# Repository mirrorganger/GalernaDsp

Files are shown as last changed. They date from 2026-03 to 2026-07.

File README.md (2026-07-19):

# Galerna DSP



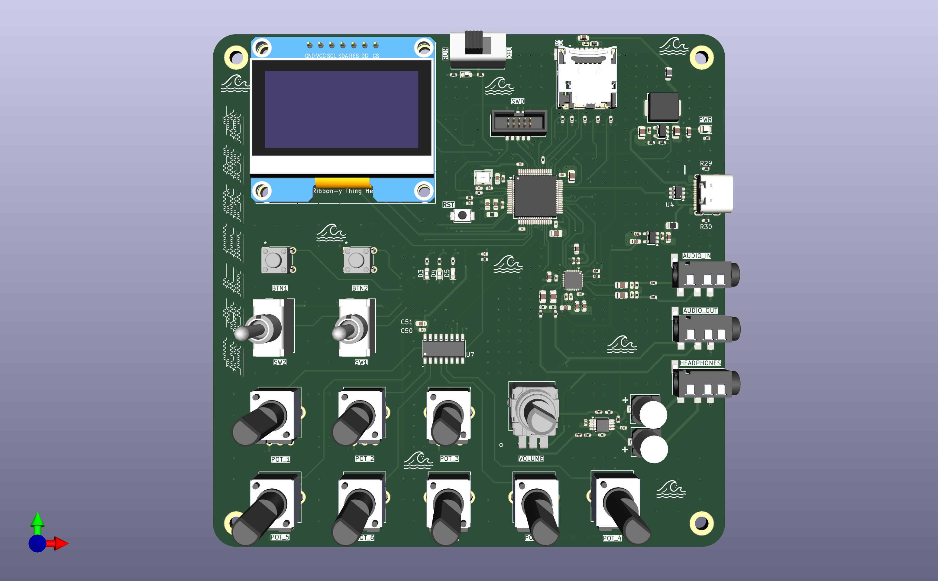
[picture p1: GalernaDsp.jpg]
Galerna DSP board render


Galerna DSP is a KiCad hardware project for an STM32-based audio effects board: two
audio channels in/out, 8 potentiometers, footswitches/buttons, an OLED display, and a
microSD slot, all built around an STM32F405.

Full design write-up — requirements, as-built BOM, power budget, codec/amp circuit
notes — lives in **[docs/Design.md](docs/Design.md)**.

## Repository layout

| Path | Contents |
|---|---|
| `GalernaDsp.kicad_pro` / `.kicad_pcb` / `.kicad_sch` | Top-level KiCad project and root schematic sheet |
| `power.kicad_sch`, `mcu.kicad_sch`, `audio_codec.kicad_sch`, `input_control.kicad_sch` | The four schematic sub-sheets |
| `libraries/Galerna/` | Project-specific KiCad symbol/footprint/3D-model library |
| `cubeMx/` | STM32CubeMX-generated firmware project for the STM32F405RGT6 (peripheral init only, no application code yet) |
| `jlcpcb/` | Manufacturing outputs for JLCPCB: gerbers, drill files, BOM/CPL for assembly |
| `docs/` | Design documentation |
| `GalernaDsp.xlsx` / `.csv` | Bill of materials |

## Opening the project

Open `GalernaDsp.kicad_pro` in KiCad (7.x). The root schematic pulls in the four
sub-sheets listed above; the PCB is a single `GalernaDsp.kicad_pcb`.

## Firmware

`cubeMx/` is a standard STM32CubeMX + CMake project. Regenerate from `cubeMx/Galerna.ioc`
in STM32CubeMX if peripheral config changes; build with CMake/CMakePresets as usual for
an STM32F4 target.

## Manufacturing

Gerbers, drill files, and JLCPCB assembly data (BOM/CPL) are pre-generated under
`jlcpcb/production_files/`.

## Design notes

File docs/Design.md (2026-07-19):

# Galerna DSP — Design

Galerna DSP is a DSP effects board based on the STM32F405, intended to process two
audio channels in real time (guitar/line-level effects unit style: pots + footswitches +
OLED status display).

This document describes the board as actually implemented in the KiCad project. Where the
build diverged from the original requirements, that's called out explicitly.

## Requirements (original intent)

- Two audio channels input/output.
- 48 kHz / up to 24-bit sample width.
- 8 potentiometers, read through a multiplexer.
- 2 mechanical switches.
- 2 buttons.
- USB-C powered.
- SWD debug.
- OLED screen.
- IO extension header.

## As-built summary

- Two audio channels in/out over I2S, plus a dedicated headphone output — a headphone
  amplifier was added, which was not in the original "no audio amplification" requirement.
- 8 potentiometers wired through a CD4051 analog mux to a single ADC input.
- 2 mechanical switches + 2 buttons for footswitch-style control.
- USB-C powered, split into a digital 3.3 V buck rail and a clean analog 3.3 V LDO rail.
- SPI OLED status display.
- microSD card slot (SDIO) for storage — not in the original requirements list.
- SWD debug and IO expansion share a single 2×5, 1.27 mm JST-GH header (CN1).
- 4-layer PCB, no analog/digital ground split, no controlled impedance (USB FS is the
  only differential pair, and it isn't critical).

## Schematic sheets

The KiCad project (`GalernaDsp.kicad_sch`) is split into four sub-sheets:

| Sheet | File | Contents |
|---|---|---|
| Power | `power.kicad_sch` | USB-C input, ESD protection, buck + LDO regulators |
| MCU | `mcu.kicad_sch` | STM32F405RGT6, crystal, OLED, microSD, IO/SWD header, reset/power switches |
| Audio | `audio_codec.kicad_sch` | Audio codec, headphone amplifier, audio jacks |
| Input Control | `input_control.kicad_sch` | 8 potentiometers, mux, footswitches, buttons |

## Bill of materials (as built)

| Function | Part | Reference(s) | Notes |
|---|---|---|---|
| Microcontroller | STM32F405RGT6 (LQFP-64) | U (mcu) | Matches original plan |
| Audio codec | **ES8388** | U (audio) | **Changed from the originally planned WM8731SEDS** during layout (see commit "Codec updated to ES8388") |
| Headphone amplifier | TPA6110A2DGN | U (audio) | Added — original requirements said "no audio amplification" |
| Headphone volume pot | RK09L12D0A1W | R16 | Local pot for headphone amp gain |
| OLED display | ER-OLEDM015-SPI | — | SPI display module; **changed from the originally planned SSD1306 part** (verify controller compatibility before reusing old pin-mapping notes) |
| Effect potentiometers ×8 | PTV09A-4225F-B104 | POT_1…POT_8 | Read through the mux below |
| Analog mux | CD4051BM | — | Routes the 8 pots to a single ADC channel |
| Mechanical switches ×2 | 100SP1T1B4M2QE | SW1, SW2 | |
| Buttons ×2 | 1825910-6 | BTN1, BTN2 | |
| Boot mode switch (RUN/DFU) | SS12D10G5 | SW_1 | Selects BOOT0 state |
| Reset button | TS-1088-AR02016 | SW_2 | |
| Audio jacks ×3 | AudioJack4 (3.5 mm) | J2, J3, J4 | Line in, line out, headphone out |
| microSD slot | HRS DM3CS-SF | J1 | Right-angle SMT microSD holder, on SDIO |
| SWD / IO expansion header | JST-GH 2×5, 1.27 mm | CN1 | Shared header for debug + expansion |
| Crystal | X1E000210127000G | X1 | MCU clock |
| USB-C receptacle | USB4105-GF-A (generic KiCad symbol) | — | |
| ESD protection (USB) | USBLC6-2SC6 | — | |
| ESD protection array (MCU IO) | RCLAMP0521P-N | — | |
| Buck regulator (digital 3V3) | TLV62569DBV | — | |
| LDO regulator (analog 3V3) | SPX3819M5-L-3-3 | — | |

Full BOM with LCSC part numbers lives in `GalernaDsp.csv` at the project root, and
JLCPCB assembly data lives in `jlcpcb/production_files/`.

## Power section

Power comes in over USB-C and is split into two 3.3 V rails:

- **3V3_D** (digital) — switching buck regulator, TLV62569DBV.
- **3V3_A** (analog) — LDO, SPX3819M5-L-3-3, feeding the codec's analog domain for lower
  noise than the buck rail could provide.

### Current budget (3.3 V rails)

| Rail | Load | Estimate |
|---|---|---|
| 3V3_D | STM32F405 | 90–130 mA |
| 3V3_D | OLED | 5–25 mA |
| 3V3_D | Mux + pullups, misc | 5–15 mA |
| 3V3_D | **Budget** | **~200 mA** |
| 3V3_A | Audio codec | ~20 mA typical |
| 3V3_A | **Budget** | **~25–50 mA** |

Total ≈ 250 mA at 3.3 V (≈ 0.83 W). At 85–92% buck efficiency that's roughly 180–200 mA
drawn from 5 V USB — comfortably inside USB power limits.

### Analog rail filtering

After the LDO, a ferrite bead plus local decoupling filters the MCU's `VDDA` pin (ferrite
beads add impedance at high frequency, keeping switching noise off the analog supply):

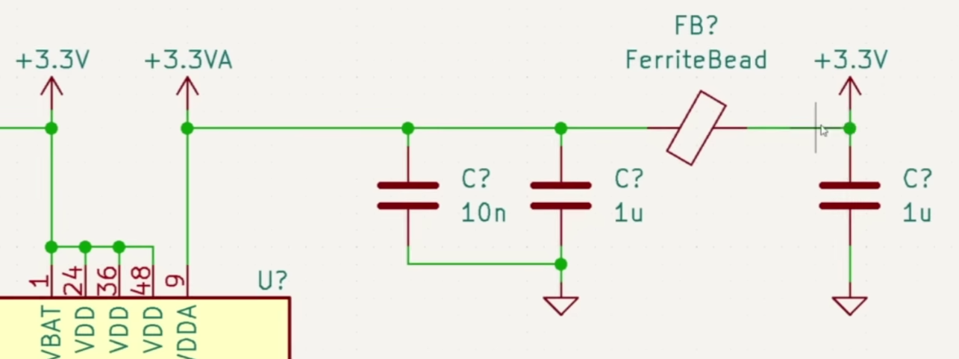
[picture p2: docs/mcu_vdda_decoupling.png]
MCU VDDA decoupling


### Buck converter inductor selection

$$
L = \frac{V_{out} \cdot (V_{in} - V_{out})}{V_{in} \cdot f_{sw} \cdot \Delta I_L}
$$

Where $\Delta I_L$ (inductor ripple current) is targeted at 20–30% of max output current.

- $V_{out} = 3.3\text{V}$, $V_{in} = 4.5$–$5\text{V}$, $f_{sw} = 1.5\text{MHz}$, $I_{max} = 250\text{mA}$
- $\Delta I_L = 0.200\text{A} \times 0.25 = 0.0625\text{A}$
- Calculated $L \approx 12\mu H$ → used a 10 µH inductor.

### Fuse options considered

- Littelfuse 0603L050YR — 500 mA hold, 0603, easiest SMT routing.
- 1206 SMD 500 mA PPTC — larger pads, easier hand/JLC assembly.
- 1210 0.5 A resettable fuse — most robust, needs more board space.

## Audio codec (ES8388)

Use LINE IN, not MIC IN.

### Decoupling

Per supply pin: 1× 100 nF MLCC at the pin (shortest loop to GND). Per rail (shared): 1×
bulk cap (4.7–10 µF) near the codec.

- Digital: 10 µF bulk + 100 nF on DVDD + 100 nF on DBVDD.
- Analog: 10 µF bulk + 100 nF on AVDD + 100 nF on HPVDD (HPVDD unused on this board).

### Input path

```
AUDIO_IN → 1k → ● → 2.2µF → CODEC_IN
                 │
                 ├─ 200k → GND
                 └─ 220p → GND
```

- **2.2 µF AC coupling**: blocks DC, lets the codec bias the input to VMID. Forms a
  high-pass with the codec's ~20–30 kΩ input impedance: $f_c \approx 3.6\text{Hz}$, well
  below the audio band.
- **200 kΩ to GND**: discharge path for the coupling cap; sets input impedance with
  nothing plugged in.
- **220 pF / 1 kΩ RF filter**: rolls off RF picked up by the cable ($f_c \approx 723\text{kHz}$);
  the resistor also limits current during ESD events.

### Output path

Concerns between the codec and the 3.5 mm jacks: DC compatibility (codec biased to
VMID ≈ 1.65 V, jack is 0 V), RF/EMI filtering, output impedance/stability, and
protection against ESD/hot-plugging.

- **AC coupling (~1 µF)**: blocks the codec's DC bias so the jack sees a signal centered
  at 0 V. Without it: DC on external gear, pops, possible damage.
- **Series resistor (~100 Ω)**: isolates the codec from cable capacitance, improves
  driver stability, reduces pop energy, limits fault current on a shorted jack.
- **Pulldown (~100 kΩ to GND)**: defines the output with nothing connected, reduces
  plug/unplug pops, negligible effect on audio level.

## Headphone amplifier (TPA6110A2DGN)

Added beyond the original spec to drive headphones directly from a dedicated 3.5 mm
jack, with its own volume pot (R16, RK09L12D0A1W). See git history for the original
routing notes; layout follows standard TPA6110 application guidance (star ground for
the amp, short high-current loops to the output caps/jack).

## Crystal oscillator

Pierce oscillator, per ST's reference circuitry:

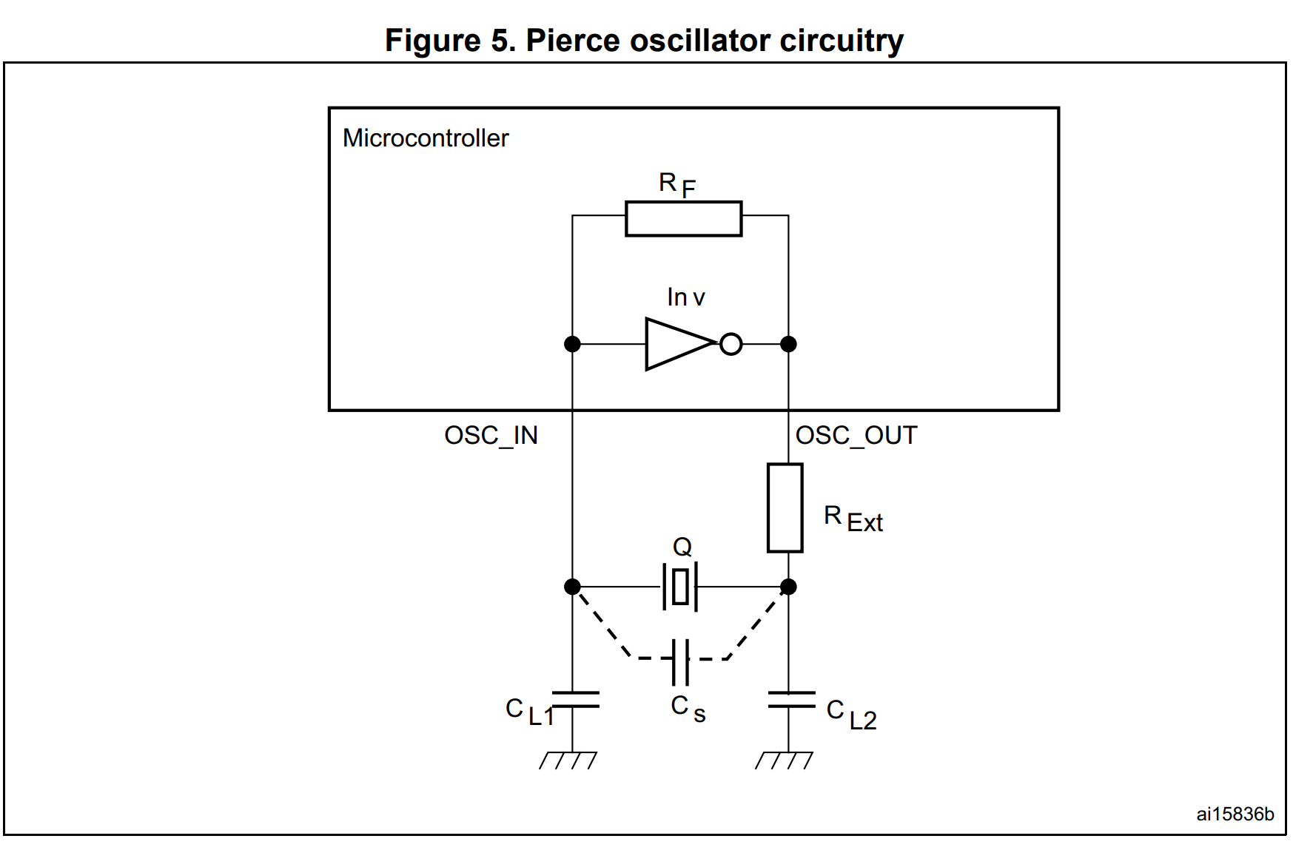
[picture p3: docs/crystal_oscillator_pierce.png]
Pierce oscillator circuitry


$R_{ext}$ and $C_L$ form a low-pass filter for harmonics above the crystal fundamental;
$R_{ext}$ also reduces drive strength over the crystal to cut harmonics.

- Values to choose: crystal (Q), load capacitance ($C_{L1}$/$C_{L2}$), $R_{ext}$.
- Values to account for: stray capacitance $C_s$ (typ. 3–5 pF), internal feedback
  resistor $R_F$.
- Example crystal: $f_0 = 16\text{MHz}$, $C_0 = 9\text{pF}$, ESR ≈ 80 Ω, 3225 package.

$$
C_L = 2 \cdot (C_0 - C_s) \approx 8\text{–}12\text{pF}
$$

$$
R_{ext} \approx 10\% \times \frac{1}{2\pi f_0 C_0} = \frac{1}{2\pi \times 24\text{MHz} \times 9\text{pF}} \approx 73\,\Omega \Rightarrow \text{100 }\Omega \text{ used}
$$

## Footprints used

| Part | Footprint |
|---|---|
| Caps 22 µF | 0805 (2012 metric) |
| Caps 10 µF | 0603 |
| Caps 1 µF | 0603 (1608 metric) |
| Caps 100 nF | 0402 (1005 metric) |
| Caps 1 nF / 10 pF | 0402 (1005 metric) |
| LEDs | 0603 or 0805 |
| Resistors | 0402 |
| Ferrite beads | 0805 or 0603 |

## PCB design notes

- 4-layer stackup: F.Cu / In1.Cu (plane) / In2.Cu (plane) / B.Cu.
- No controlled impedance needed — the only differential pair is USB FS, and it isn't
  critical.
- No split ground plane between analog and digital.
- Connectors for GPIO expansion use JST-GH.
- microSD placement followed the LeDsp module's layout as a reference.
- **J5 (USB-C receptacle) intentionally diverges from the stock `Connector_USB` library
  footprint**: its two unnamed NPTH mounting/alignment holes are set to `*.Cu` (all
  copper layers) instead of the library default `F&B.Cu` (front/back only). The board's
  GND plane (net `GND`) is poured across both inner layers (`In1.Cu`/`In2.Cu`) under the
  full connector area, so widening those pads to `*.Cu` is required to get proper copper
  clearance around the mounting holes on the inner layers during zone fill — with the
  library default, the plane would pour solid copper straight across the drilled holes
  on `In1.Cu`/`In2.Cu` with no clearance. This shows up as a `lib_footprint_mismatch` DRC
  warning; it's expected and should be excluded rather than "fixed" back to the library
  footprint.

## Firmware status

`cubeMx/` holds an STM32CubeMX-generated project for the STM32F405RGT6 with ADC1, I2C2
(codec control), I2S2 (audio data), SDIO (microSD), SPI1 (OLED), and USB_OTG_FS
configured. As of now it's the generated peripheral-init skeleton only — no DSP effect
processing has been implemented in application code yet.

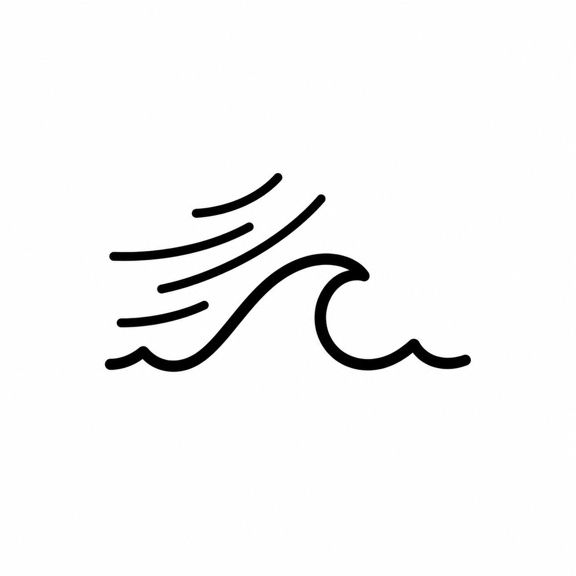
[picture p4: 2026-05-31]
olas/ola-3.png

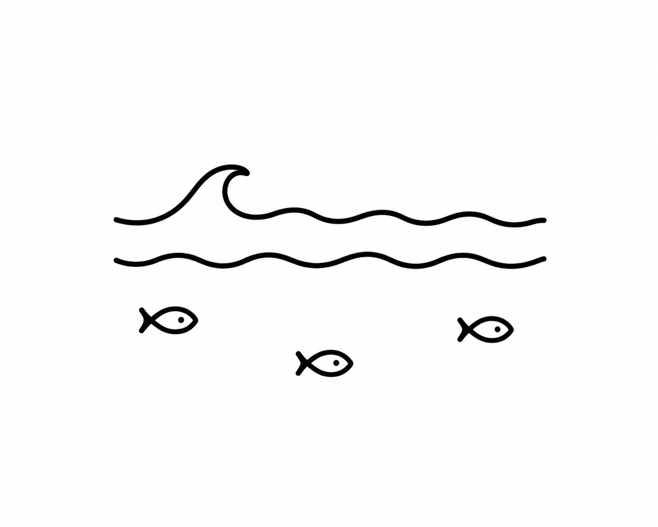
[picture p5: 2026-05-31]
olas/ola-6.png

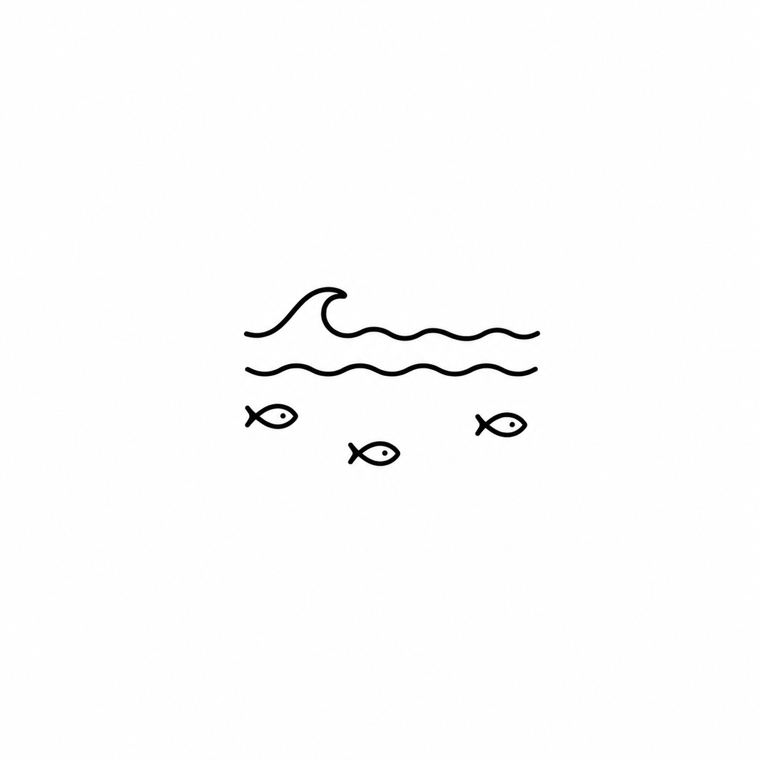
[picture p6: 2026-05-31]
olas/ola-5.png

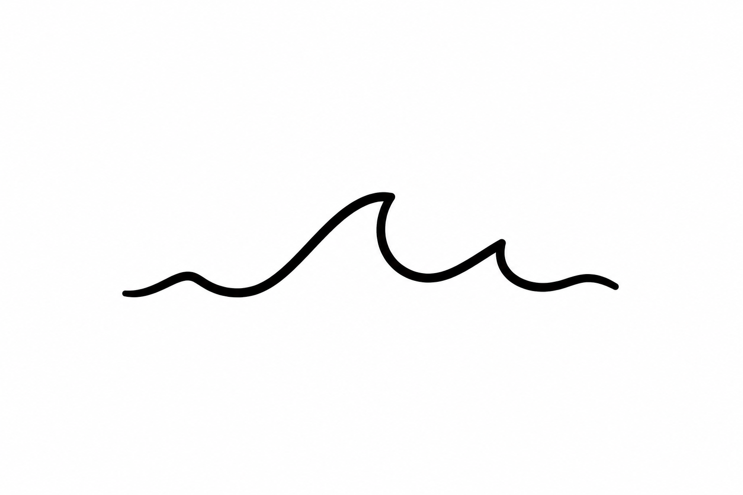
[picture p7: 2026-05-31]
olas/ola-2.png

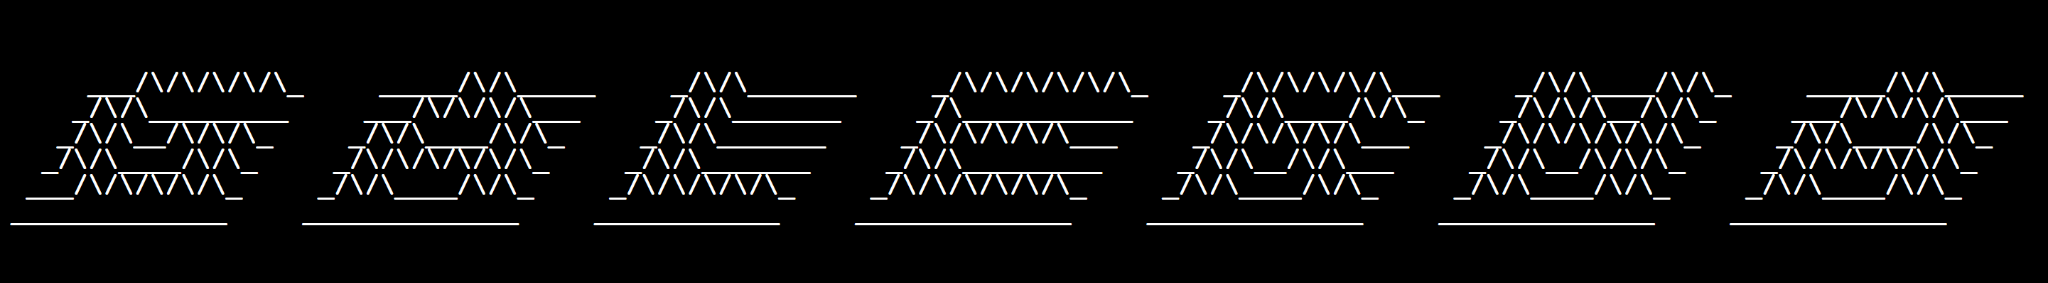
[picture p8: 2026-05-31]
olas/image.png

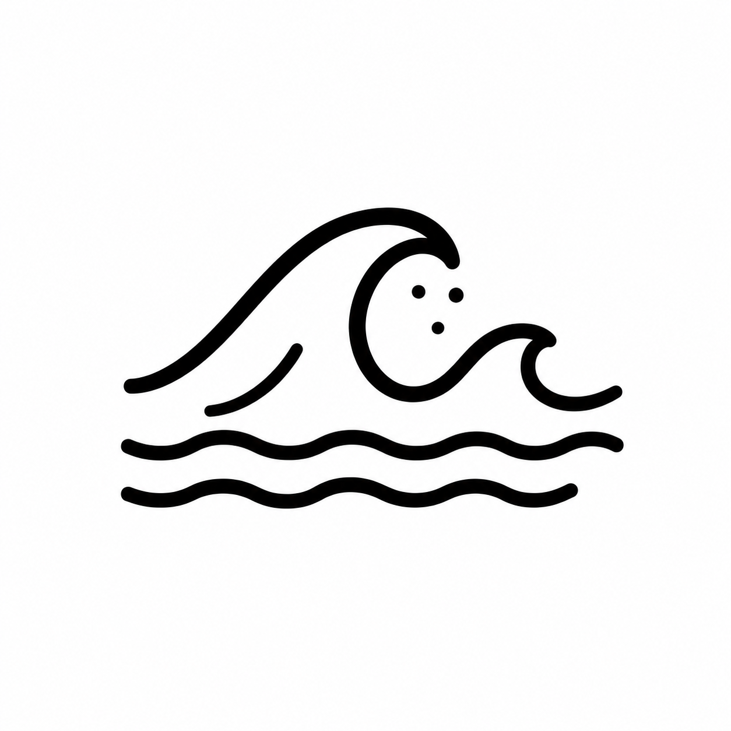
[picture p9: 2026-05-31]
olas/ola-4.png

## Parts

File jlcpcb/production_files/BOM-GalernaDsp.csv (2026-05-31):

Comment | Designator | Footprint | LCSC | Quantity
100 | R25,R26 | R_0402_1005Metric | C25076 | 2
100@100MHz | FB1 | L_0805_2012Metric | C1015 | 1
100SP1T1B4M2QE | SW1,SW2 | SW_100SP1T1B4M2QE | C273353 | 2
100k | R31 | R_0402_1005Metric | C25741 | 1
100n | C11,C12,C18,C21,C25,C26,C27,C28,C3,C31,C33,C34,C43,C44,C5,C50,C52,C6,C7,C9 | C_0402_1005Metric | C1525 | 20
100u | C35,C36 | CHEMI-F80 | C2162906 | 2
10k | R10,R2,R3,R6,R7,R8,R9 | R_0402_1005Metric | C25744 | 7
10n | C13,C47 | C_0402_1005Metric | C15195 | 2
10u | L2 | L_Sunlord_MWSA0618S | C132135 | 1
10u | C14,C16,C19,C20,C22,C23,C24,C32,C4,C46,C48,C51 | C_0603_1608Metric | C19702 | 12
120@100Mhz | FB3 | R_0603_1608Metric | C14709 | 1
12p | C1,C2 | C_0402_1005Metric | C1547 | 2
1825910-6 | BTN1,BTN2 | SW4_1825910-B_TEC | C428628 | 2
1k | R1,R11,R12,R13,R27,R28,R34 | R_0402_1005Metric | C11702 | 7
1k5 | R33 | R_0402_1005Metric | C25867 | 1
1u | C15,C17 | C_0603_1608Metric | C15849 | 2
1u | C29,C30 | C_0402_1005Metric | C52923 | 2
2.2u | C10,C37,C38,C39,C40,C8 | C_0805_2012Metric | C377773 | 6
200k | R21,R22 | R_0402_1005Metric | C25764 | 2
22 | R5 | R_0402_1005Metric | C25092 | 1
220p | C41,C42 | C_0402_1005Metric | C1530 | 2
22k | R17,R18,R32 | R_0402_1005Metric | C25768 | 3
22u | C45,C49 | C_0805_2012Metric | C45783 | 2
33k | R19,R20 | R_0402_1005Metric | C25779 | 2
47k | R23,R24,R4 | R_0402_1005Metric | C25792 | 3
4k7 | R14,R15 | R_0402_1005Metric | C25900 | 2
5k1 | R29,R30 | R_0402_1005Metric | C25905 | 2
600Ω@100MHz | FB2 | R_0805_2012Metric | C1017 | 1
JACK | J2,J3,J4 | AUDIO-SMD_PJ-320D-1 | C431535 | 1
BOOT_MODE | SW_1 | SW-TH_SHOU-HAN_SS12D10G4 | C7431054 | 1
CD4051BM | U7 | SOIC127P600X175-16N | C21379 | 1
DM3CS-SF | J1 | HRS_DM3CS-SF | C202111 | 1
ES8388 | U2 | ES8388 | C365736 | 1
GREEN LED | D6 | LED_0805_2012Metric | C2297 | 1
HX JN1.27-2X5 TP H4.9 | CN1 | IDC-SMD_10P-P1.27-3220-10-0300-00 | C42372555 | 1
PTV09A-4225F-B104 | POT_1,POT_2,POT_3,POT_4,POT_5,POT_6,POT_7,POT_8 | PTV09 | C5848796 | 8
RCLAMP0521P-N | D2 | X1-DFN1006-2_L1.0-W0.6-P0.65-BI | C316043 | 1
RED | D1 | LED_0603_1608Metric | C2286 | 1
RK09L12D0A1W | R16 | RK09L12D0A1W_AAL | C470487 | 1
SPX3819M5-L-3-3 | U6 | SOT-23-5 | C20617301 | 1
STM32F405RGTx | U1 | LQFP-64_10x10mm_P0.5mm | C15742 | 1
SW_RESET | SW_2 | SW-SMD_L3.9-W3.0-P4.45 | C720477 | 1
TLV62569DBV | U5 | SOT-23-5 | C141836 | 1
TPA6110A2DGN | U3 | HVSSOP-8-1EP_3x3mm_P0.65mm_EP1.57x1.89mm | C130212 | 1
USBLC6-2SC6 | U4 | SOT-23-6 | C7519 | 1
USB_C_Receptacle_USB2.0_16P | J5 | USB_C_Receptacle_GCT_USB4105-xx-A_16P_TopMnt_Horizontal | C2765186 | 1
X1E000210127000G | X1 | CRYSTAL-SMD_4P-L3.2-W2.5-BL | C89577 | 1
YELLOW_LED | D3,D4,D5 | LED_0603_1608Metric | C2290 | 3

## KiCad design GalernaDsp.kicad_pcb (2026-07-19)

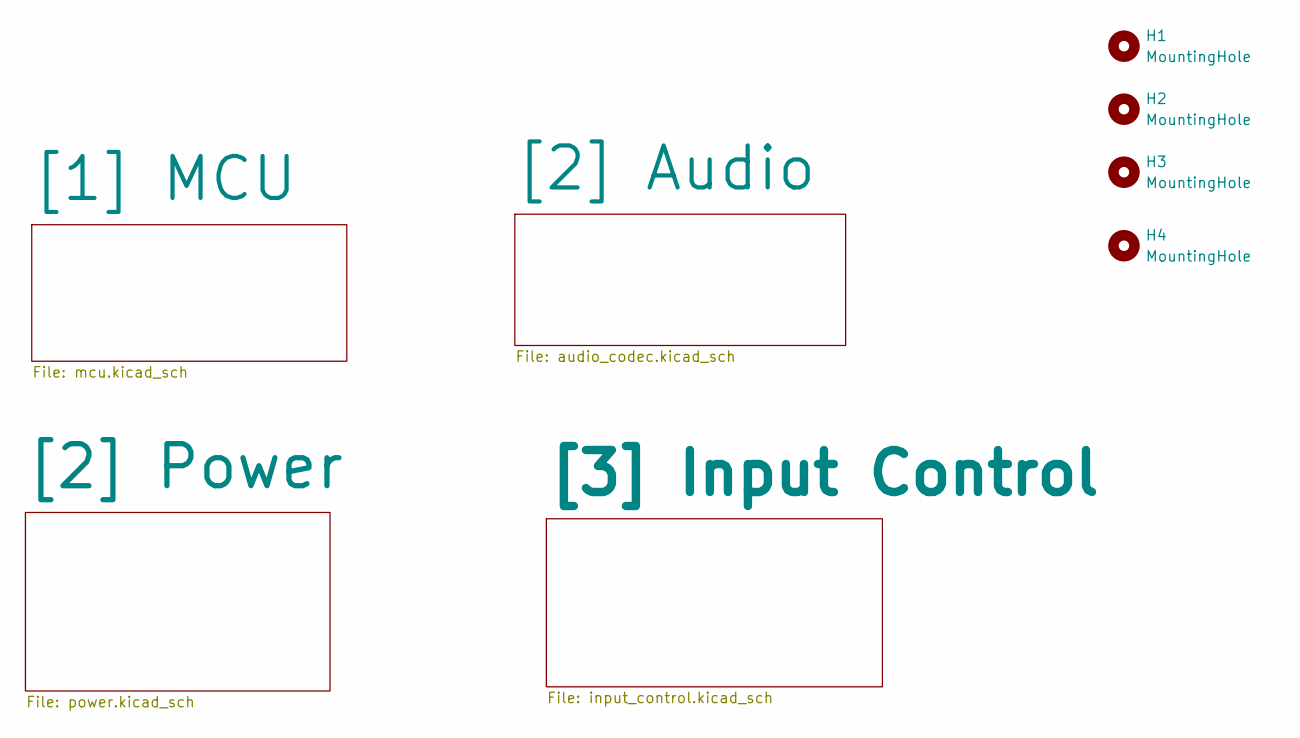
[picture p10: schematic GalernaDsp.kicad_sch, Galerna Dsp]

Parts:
H1, H2, H3, H4: MountingHole; MountingHole_3.2mm_M3_DIN965_Pad_TopBottom

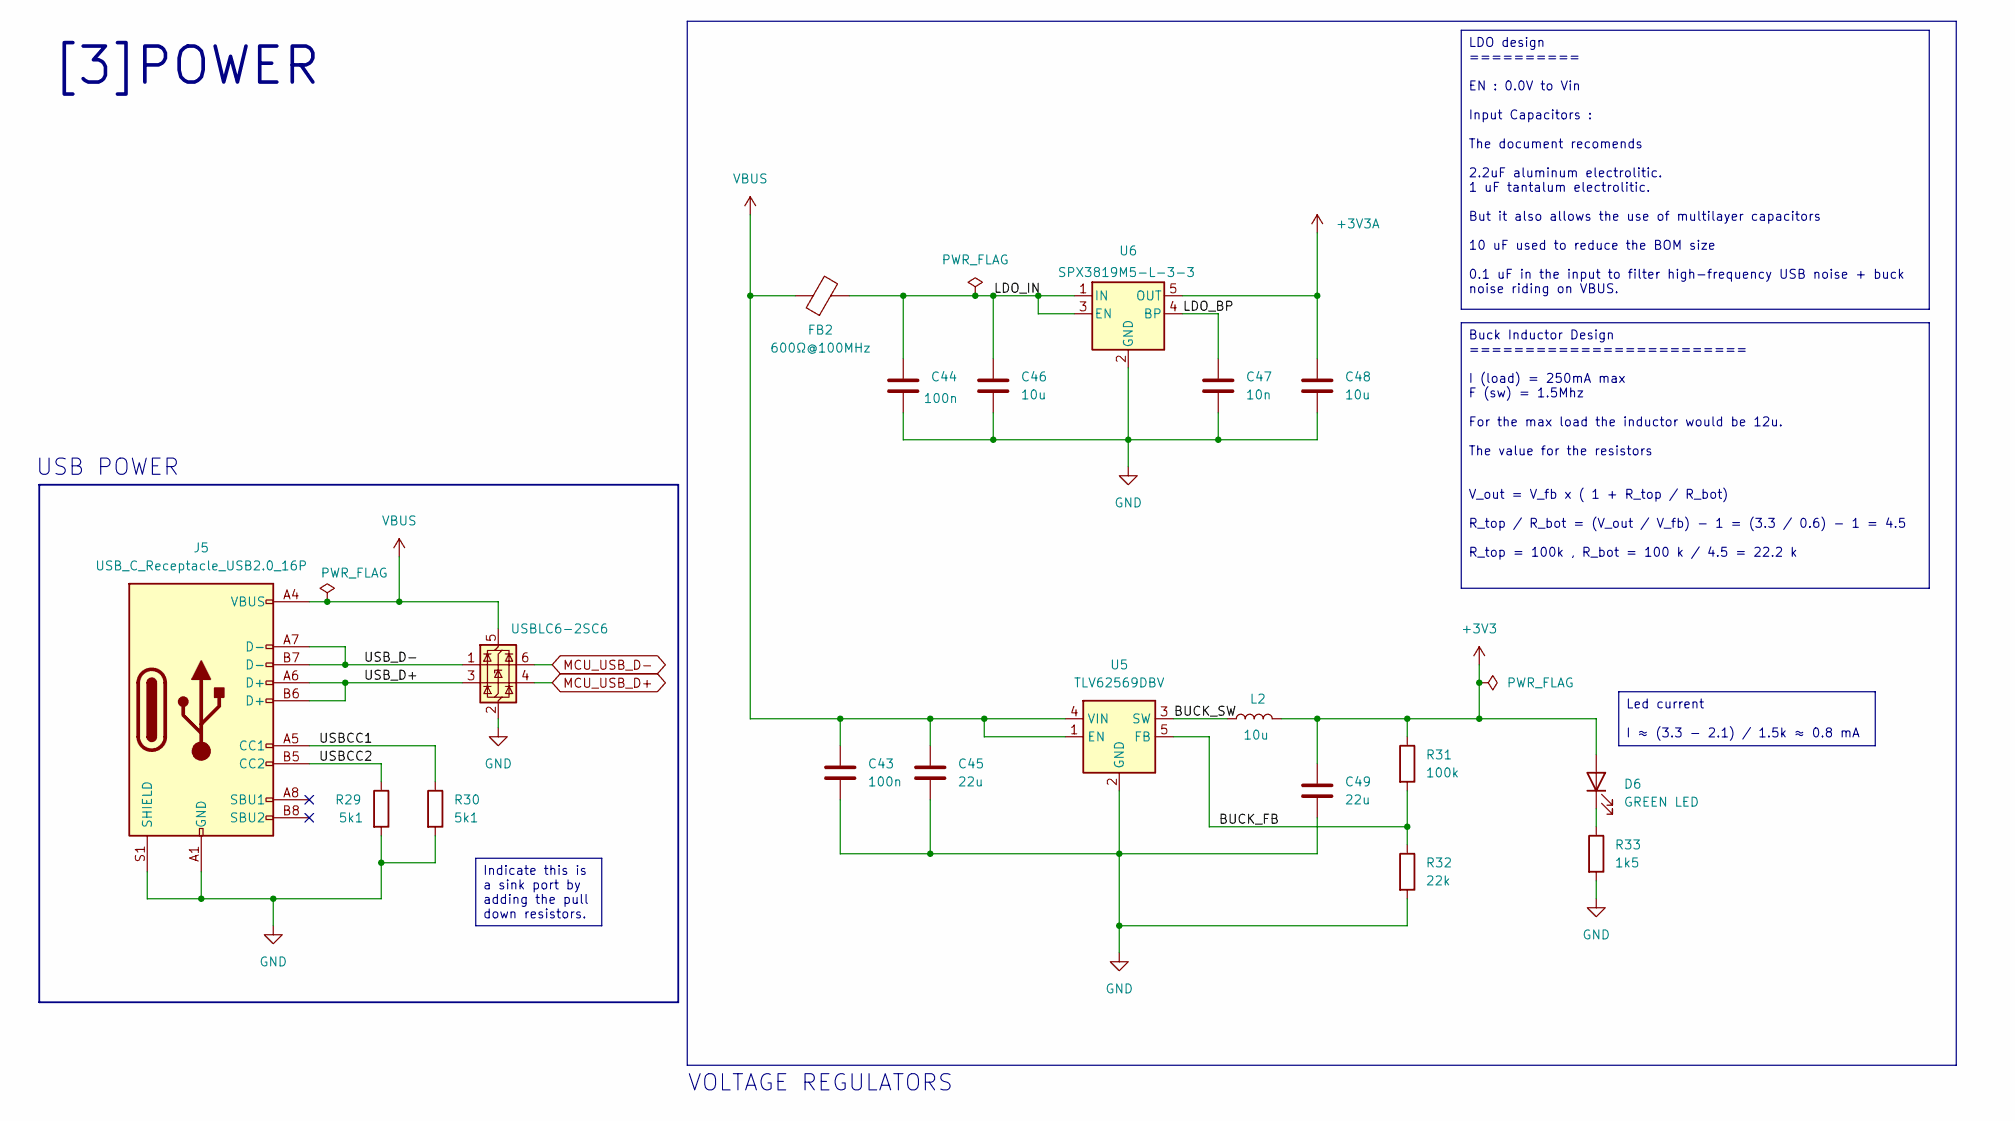
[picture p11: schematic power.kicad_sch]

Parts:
C43, C44: 100n; C_0402_1005Metric
C45, C49: 22u; C_0805_2012Metric
C46, C48: 10u; C_0603_1608Metric
C47: 10n; C_0402_1005Metric
D6: GREEN LED; LED_0805_2012Metric
FB2: 600Ω@100MHz; R_0805_2012Metric; Manufacturer Part GZ2012D601TF; LCSC Part C1017
J5: USB_C_Receptacle_USB2.0_16P; USB_C_Receptacle_GCT_USB4105-xx-A_16P_TopMnt_Horizontal; Manufacturer Part TYPE-C 16PIN 2MD(073); LCSC Part C2765186
L2: 10u; L_Sunlord_MWSA0618S; Manufacturer Part MWSA0618S-100MT; LCSC Part C132135
R29, R30: 5k1; R_0402_1005Metric
R31: 100k; R_0402_1005Metric
R32: 22k; R_0402_1005Metric
R33: 1k5; R_0402_1005Metric
U4: USBLC6-2SC6; SOT-23-6; Manufacturer Part USBLC6-2SC6; LCSC Part C7519
U5: TLV62569DBV; SOT-23-5; Manufacturer Part TLV62569DBVR; LCSC Part C141836
U6: SPX3819M5-L-3-3; SOT-23-5; Manufacturer Part SPX3819M5-L-3-3; LCSC Part C20617301

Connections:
+3V3: C49.1, D6.2 (A), L2.2, R31.1; also elsewhere on the board
+3V3A: C48.1, U6.5 (OUT); also elsewhere on the board
/[2] Power/BUCK_FB: R31.2, R32.1, U5.5 (FB)
/[2] Power/BUCK_SW: L2.1, U5.3 (SW)
/[2] Power/LDO_BP: C47.1, U6.4 (BP)
/[2] Power/LDO_IN: C44.1, C46.1, FB2.2, U6.1 (IN), U6.3 (EN)
/[2] Power/USBCC1: J5.A5 (CC1), R30.1
/[2] Power/USBCC2: J5.B5 (CC2), R29.1
/[2] Power/USB_D+: J5.A6 (D+), J5.B6 (D+), U4.3 (I/O2)
/[2] Power/USB_D-: J5.A7 (D-), J5.B7 (D-), U4.1 (I/O1)
GND: C43.2, C44.2, C45.2, C46.2, C47.2, C48.2, C49.2, J5.A1 (GND), J5.A12 (GND), J5.B1 (GND), J5.B12 (GND), J5.S1 (SHIELD), R29.2, R30.2, R32.2, R33.2, U4.2 (GND), U5.2 (GND), U6.2 (GND); also elsewhere on the board
MCU_USB_D+: U4.4 (I/O2); also elsewhere on the board
MCU_USB_D-: U4.6 (I/O1); also elsewhere on the board
unnamed: D6.1 (K), R33.1
VBUS: C43.1, C45.1, FB2.1, J5.A4 (VBUS), J5.A9 (VBUS), J5.B4 (VBUS), J5.B9 (VBUS), U4.5 (VBUS), U5.1 (EN), U5.4 (VIN)

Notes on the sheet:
VOLTAGE REGULATORS
USB POWER
[3]POWER
Indicate this is a sink port by adding the pull down resistors.
Led current I ≈ (3.3 - 2.1) / 1.5k ≈ 0.8 mA
LDO design ========== EN : 0.0V to Vin Input Capacitors : The document recomends 2.2uF aluminum electrolitic. 1 uF tantalum electrolitic. But it also allows the use of multilayer capacitors 10 uF used to reduce the BOM size 0.1 uF in the input to filter high-frequency USB noise + buck noise riding 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
Buck Inductor Design ========================= I (load) = 250mA max F (sw) = 1.5Mhz For the max load the inductor would be 12u. The value for the resistors V_out = V_fb x ( 1 + R_top / R_bot) R_top / R_bot = (V_out / V_fb) - 1 = (3.3 / 0.6) - 1 = 4.5 R_top = 100k , R_bot = 100 k / 4.5 = 22.2 k

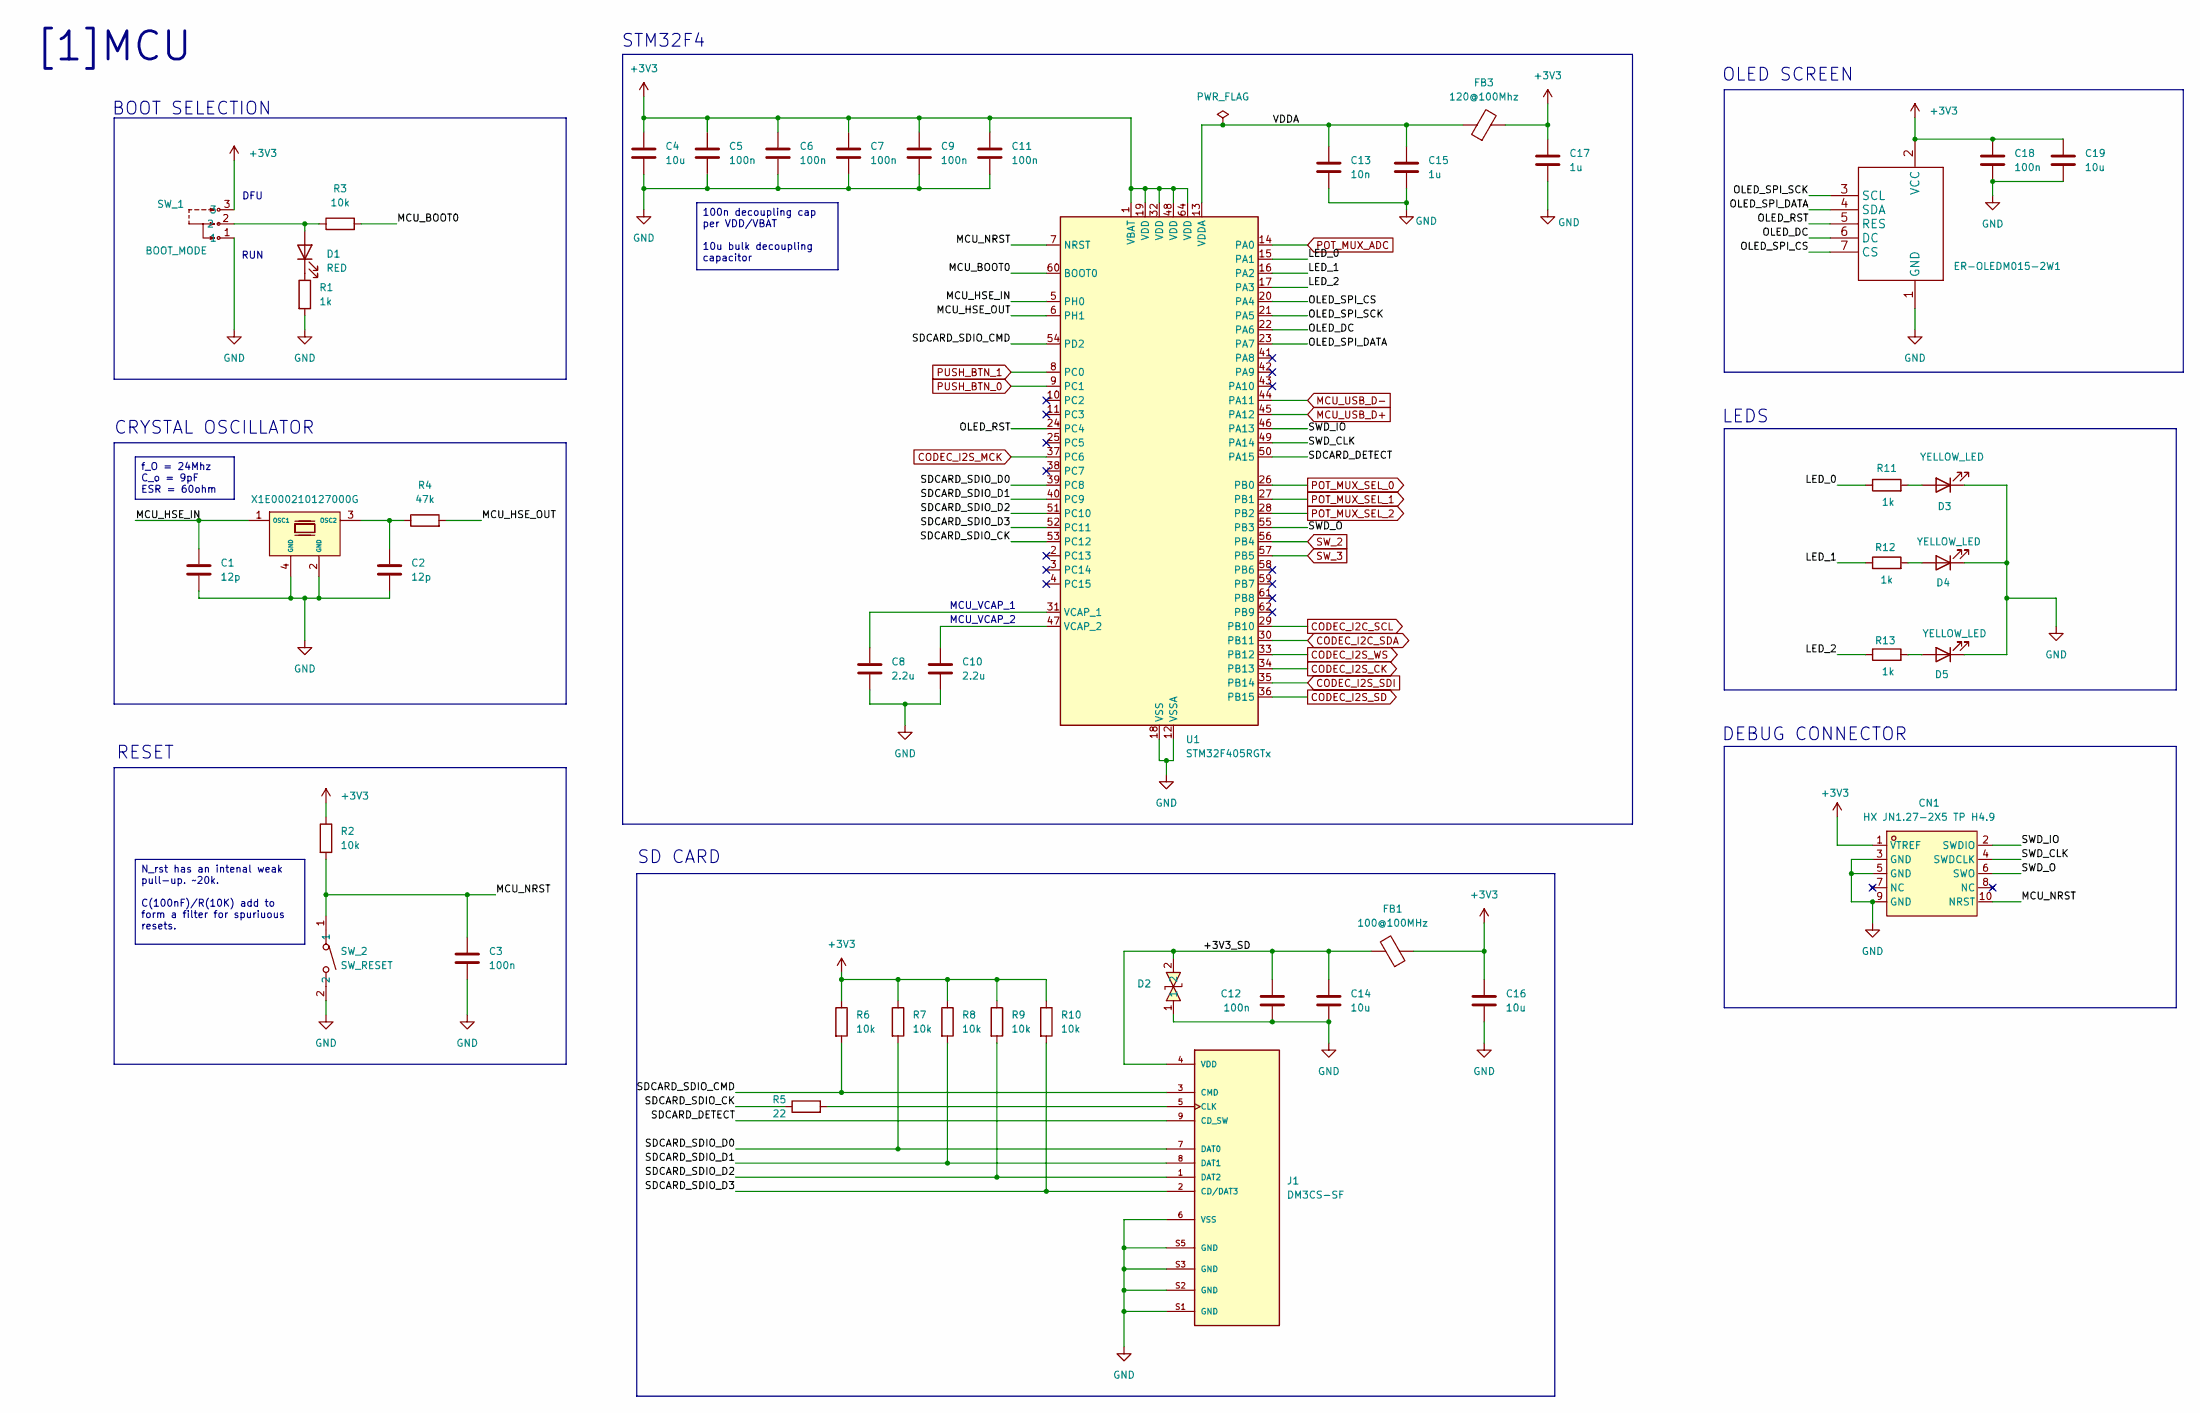
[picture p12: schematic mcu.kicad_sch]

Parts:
C1, C2: 12p; C_0402_1005Metric
C3, C5, C6, C7, C9, C11, C12, C18: 100n; C_0402_1005Metric
C4, C14, C16, C19: 10u; C_0603_1608Metric
C8, C10: 2.2u; C_0805_2012Metric
C13: 10n; C_0402_1005Metric
C15, C17: 1u; C_0603_1608Metric
CN1: HX JN1.27-2X5 TP H4.9; IDC-SMD_10P-P1.27-3220-10-0300-00; Manufacturer Part HX JN1.27-2x5 TP H4.9; LCSC Part C42372555
D1: RED; LED_0603_1608Metric
D2: RCLAMP0521P-N; X1-DFN1006-2_L1.0-W0.6-P0.65-BI; Manufacturer Part RCLAMP0521P-N; LCSC Part C316043
D3, D4, D5: YELLOW_LED; LED_0603_1608Metric
ER-OLEDM015-2W1: ER-OLEDM015-2
FB1: 100@100MHz; L_0805_2012Metric
FB3: 120@100Mhz; R_0603_1608Metric
J1: DM3CS-SF; HRS_DM3CS-SF; PARTREV n/a; LCSC Part C202111
R1: 1k; R_0402_1005Metric; Manufacturer Part 0402WGF1001TCE; LCSC Part C11702
R2, R3, R6, R7, R8, R9, R10: 10k; R_0402_1005Metric
R4: 47k; R_0402_1005Metric
R5: 22; R_0402_1005Metric
R11, R12, R13: 1k; R_0402_1005Metric
SW_1: BOOT_MODE; SW-TH_SHOU-HAN_SS12D10G4; Manufacturer Part SS12D10G5; LCSC Part C7431054
SW_2: SW_RESET; SW-SMD_L3.9-W3.0-P4.45; Manufacturer Part TS-1088-AR02016; LCSC Part C720477
U1: STM32F405RGTx; LQFP-64_10x10mm_P0.5mm; Manufacturer Part STM32F405RGT6; LCSC Part C15742
X1: X1E000210127000G; CRYSTAL-SMD_4P-L3.2-W2.5-BL; Manufacturer Part X1E0000210127; LCSC Part C89577

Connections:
+3V3: C4.1, C5.1, C6.1, C7.1, C9.1, C11.1, C16.1, C17.1, C18.1, C19.1, CN1.1 (VTREF), ER-OLEDM015-2W1.2 (VCC), FB1.1, FB3.2, R2.1, R6.1, R7.1, R8.1, R9.1, R10.1, SW_1.3, U1.1 (VBAT), U1.19 (VDD), U1.32 (VDD), U1.48 (VDD), U1.64 (VDD); also elsewhere on the board
/[1] MCU/+3V3_SD: C12.1, C14.1, D2.2, FB1.2, J1.4 (VDD)
/[1] MCU/LED_0: R11.1, U1.15 (PA1)
/[1] MCU/LED_1: R12.1, U1.16 (PA2)
/[1] MCU/LED_2: R13.1, U1.17 (PA3)
/[1] MCU/MCU_BOOT0: R3.2, U1.60 (BOOT0)
/[1] MCU/MCU_HSE_IN: C1.1, U1.5 (PH0), X1.1 (OSC1)
/[1] MCU/MCU_HSE_OUT: R4.2, U1.6 (PH1)
/[1] MCU/MCU_NRST: C3.1, CN1.10 (NRST), R2.2, SW_2.1, U1.7 (NRST)
/[1] MCU/OLED_DC: ER-OLEDM015-2W1.6 (DC), U1.22 (PA6)
/[1] MCU/OLED_RST: ER-OLEDM015-2W1.5 (RES), U1.24 (PC4)
/[1] MCU/OLED_SPI_CS: ER-OLEDM015-2W1.7 (CS), U1.20 (PA4)
/[1] MCU/OLED_SPI_DATA: ER-OLEDM015-2W1.4 (SDA), U1.23 (PA7)
/[1] MCU/OLED_SPI_SCK: ER-OLEDM015-2W1.3 (SCL), U1.21 (PA5)
/[1] MCU/SDCARD_DETECT: J1.9 (CD_SW), U1.50 (PA15)
/[1] MCU/SDCARD_SDIO_CK: R5.1, U1.53 (PC12)
/[1] MCU/SDCARD_SDIO_CMD: J1.3 (CMD), R6.2, U1.54 (PD2)
/[1] MCU/SDCARD_SDIO_D0: J1.7 (DAT0), R7.2, U1.39 (PC8)
/[1] MCU/SDCARD_SDIO_D1: J1.8 (DAT1), R8.2, U1.40 (PC9)
/[1] MCU/SDCARD_SDIO_D2: J1.1 (DAT2), R9.2, U1.51 (PC10)
/[1] MCU/SDCARD_SDIO_D3: J1.2 (CD/DAT3), R10.2, U1.52 (PC11)
/[1] MCU/SWD_CLK: CN1.4 (SWDCLK), U1.49 (PA14)
/[1] MCU/SWD_IO: CN1.2 (SWDIO), U1.46 (PA13)
/[1] MCU/SWD_O: CN1.6 (SWO), U1.55 (PB3)
/[1] MCU/VDDA: C13.1, C15.1, FB3.1, U1.13 (VDDA)
CODEC_I2C_SCL: U1.29 (PB10); also elsewhere on the board
CODEC_I2C_SDA: U1.30 (PB11); also elsewhere on the board
CODEC_I2S_CK: U1.34 (PB13); also elsewhere on the board
CODEC_I2S_MCK: U1.37 (PC6); also elsewhere on the board
CODEC_I2S_SD: U1.36 (PB15); also elsewhere on the board
CODEC_I2S_SDI: U1.35 (PB14); also elsewhere on the board
CODEC_I2S_WS: U1.33 (PB12); also elsewhere on the board
GND: C1.2, C2.2, C3.2, C4.2, C5.2, C6.2, C7.2, C8.2, C9.2, C10.2, C11.2, C12.2, C13.2, C14.2, C15.2, C16.2, C17.2, C18.2, C19.2, CN1.3 (GND), CN1.5 (GND), CN1.9 (GND), D2.1, D3.1 (K), D4.1 (K), D5.1 (K), ER-OLEDM015-2W1.1 (GND), J1.6 (VSS), J1.S1 (GND), J1.S2 (GND), J1.S3 (GND), J1.S5 (GND), R1.2, SW_1.1, SW_2.2, U1.12 (VSSA), U1.18 (VSS), U1.63 (VSS), X1.2 (GND), X1.4 (GND); also elsewhere on the board
MCU_USB_D+: U1.45 (PA12); also elsewhere on the board
MCU_USB_D-: U1.44 (PA11); also elsewhere on the board
unnamed: D1.2 (A), R3.1, SW_1.2
unnamed: D1.1 (K), R1.1
unnamed: D3.2 (A), R11.2
unnamed: D4.2 (A), R12.2
unnamed: D5.2 (A), R13.2
unnamed: J1.5 (CLK), R5.2
unnamed: C8.1, U1.31 (VCAP_1)
unnamed: C10.1, U1.47 (VCAP_2)
unnamed: C2.1, R4.1, X1.3 (OSC2)
POT_MUX_ADC: U1.14 (PA0); also elsewhere on the board
POT_MUX_SEL_0: U1.26 (PB0); also elsewhere on the board
POT_MUX_SEL_1: U1.27 (PB1); also elsewhere on the board
POT_MUX_SEL_2: U1.28 (PB2); also elsewhere on the board
PUSH_BTN_0: U1.9 (PC1); also elsewhere on the board
PUSH_BTN_1: U1.8 (PC0); also elsewhere on the board
SW_2: U1.56 (PB4); also elsewhere on the board
SW_3: U1.57 (PB5); also elsewhere on the board

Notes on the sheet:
[1]MCU
RUN
BOOT SELECTION
SD CARD
LEDS
MCU_VCAP_2
DEBUG CONNECTOR
RESET
OLED SCREEN
STM32F4
MCU_VCAP_1
CRYSTAL OSCILLATOR
DFU
100n decoupling cap per VDD/VBAT 10u bulk decoupling capacitor
f_O = 24Mhz C_o = 9pF ESR = 60ohm
N_rst has an intenal weak pull-up. ~20k. C(100nF)/R(10K) add to form a filter for spuriuous resets.

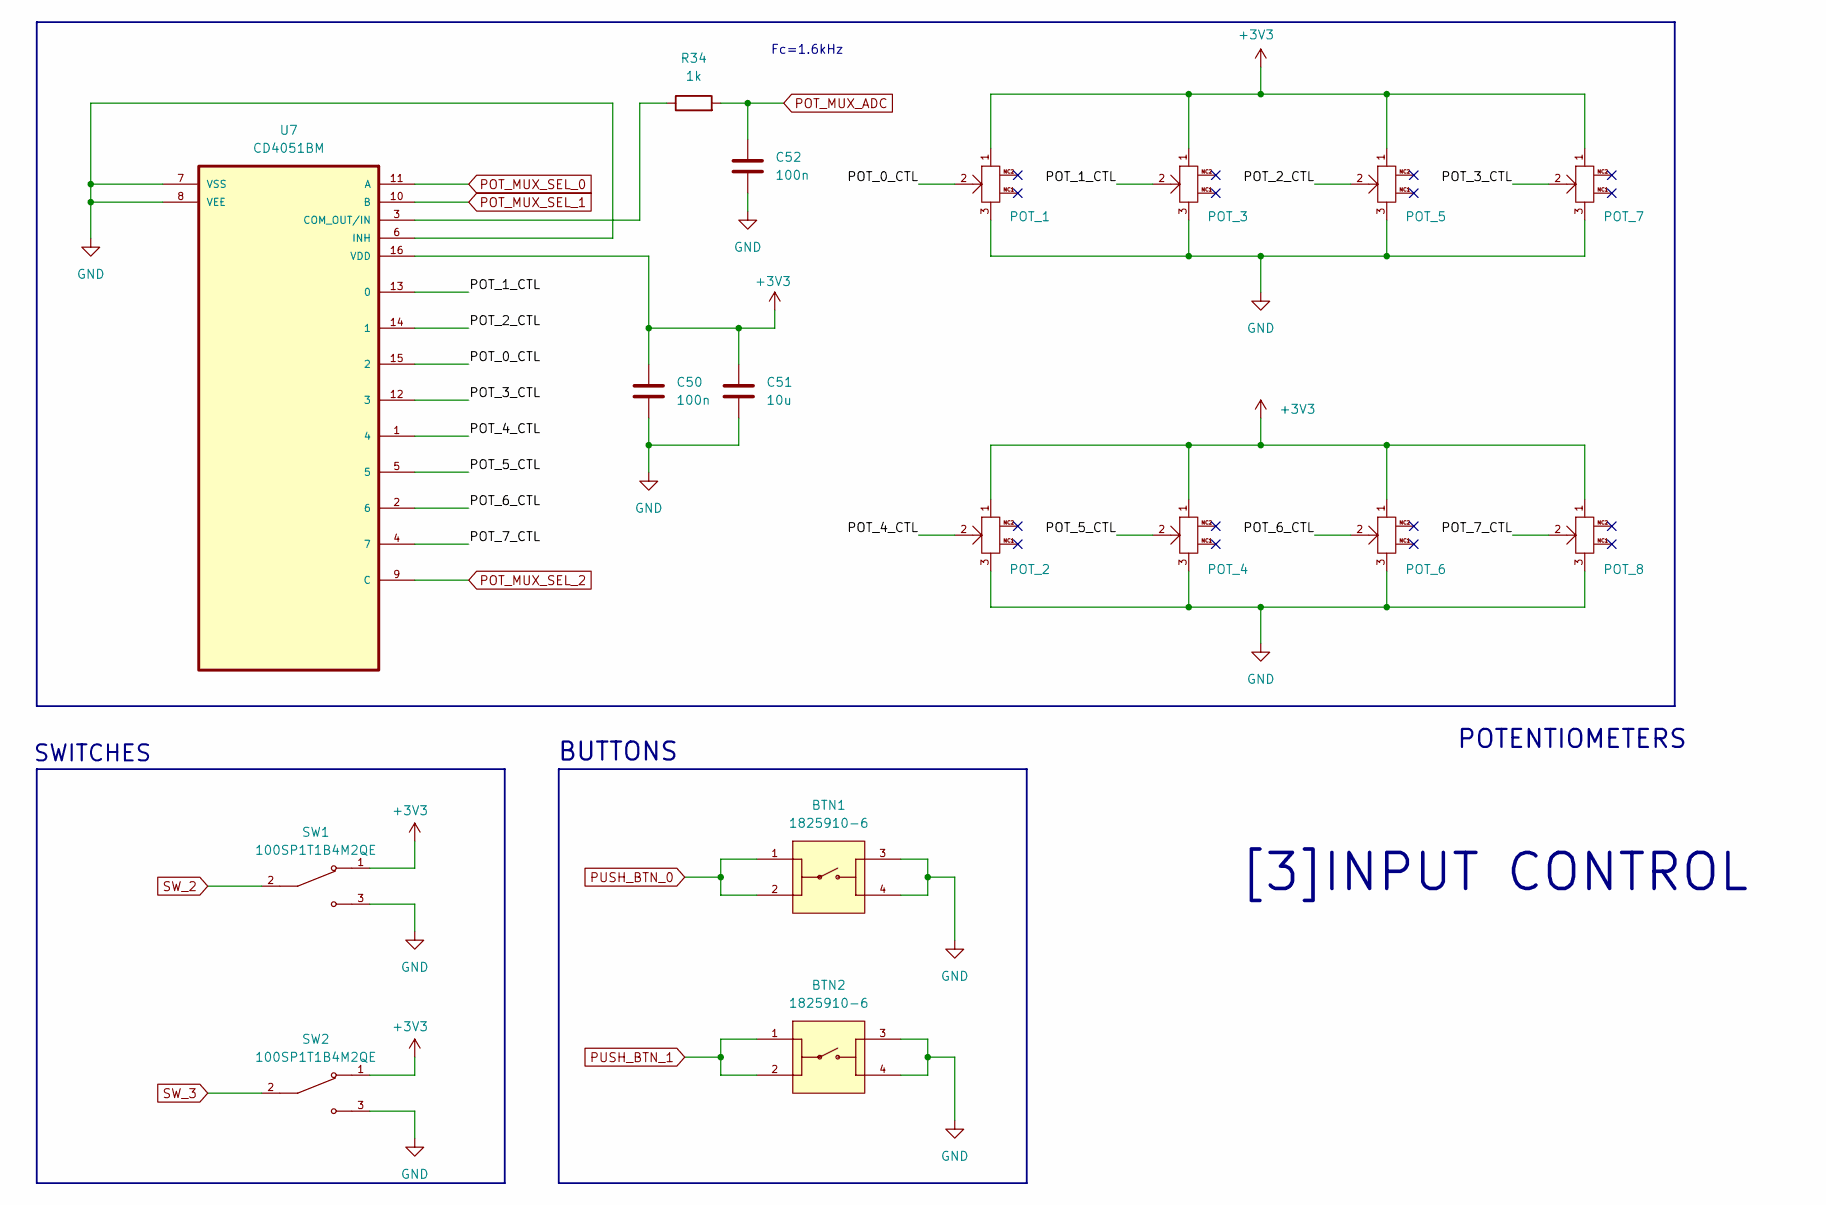
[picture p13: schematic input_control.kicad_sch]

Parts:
BTN1, BTN2: 1825910-6; SW4_1825910-B_TEC; PARTREV C10
C50, C52: 100n; C_0402_1005Metric
C51: 10u; C_0603_1608Metric
POT_1, POT_2, POT_3, POT_4, POT_5, POT_6, POT_7, POT_8: PTV09A-4225F-B104; PTV09; PARTNO PTV09A-4225F-B104-ND; LCSC Part C5848796
R34: 1k; R_0402_1005Metric; Manufacturer Part 0402WGF1001TCE; LCSC Part C11702
SW1, SW2: 100SP1T1B4M2QE; SW_100SP1T1B4M2QE; PARTREV E; LCSC Part C273353
U7: CD4051BM; SOIC127P600X175-16N; Manufacturer Part CD4051BM96; LCSC Part C21379

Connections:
+3V3: C50.1, C51.1, POT_1.1, POT_2.1, POT_3.1, POT_4.1, POT_5.1, POT_6.1, POT_7.1, POT_8.1, SW1.1, SW2.1, U7.16 (VDD); also elsewhere on the board
/[3] Input Control/POT_0_CTL: POT_1.2, U7.15 (2)
/[3] Input Control/POT_1_CTL: POT_3.2, U7.13 (0)
/[3] Input Control/POT_2_CTL: POT_5.2, U7.14 (1)
/[3] Input Control/POT_3_CTL: POT_7.2, U7.12 (3)
/[3] Input Control/POT_4_CTL: POT_2.2, U7.1 (4)
/[3] Input Control/POT_5_CTL: POT_4.2, U7.5
/[3] Input Control/POT_6_CTL: POT_6.2, U7.2 (6)
/[3] Input Control/POT_7_CTL: POT_8.2, U7.4 (7)
GND: BTN1.3, BTN1.4, BTN2.3, BTN2.4, C50.2, C51.2, C52.2, POT_1.3, POT_2.3, POT_3.3, POT_4.3, POT_5.3, POT_6.3, POT_7.3, POT_8.3, SW1.3, SW2.3, U7.6 (INH), U7.7 (VSS), U7.8 (VEE); also elsewhere on the board
unnamed: R34.1, U7.3 (COM_OUT/IN)
POT_MUX_ADC: C52.1, R34.2; also elsewhere on the board
POT_MUX_SEL_0: U7.11 (A); also elsewhere on the board
POT_MUX_SEL_1: U7.10 (B); also elsewhere on the board
POT_MUX_SEL_2: U7.9 (C); also elsewhere on the board
PUSH_BTN_0: BTN1.1, BTN1.2; also elsewhere on the board
PUSH_BTN_1: BTN2.1, BTN2.2; also elsewhere on the board
SW_2: SW1.2; also elsewhere on the board
SW_3: SW2.2; also elsewhere on the board

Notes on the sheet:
BUTTONS
SWITCHES
POTENTIOMETERS
[3]INPUT CONTROL
Fc=1.6kHz

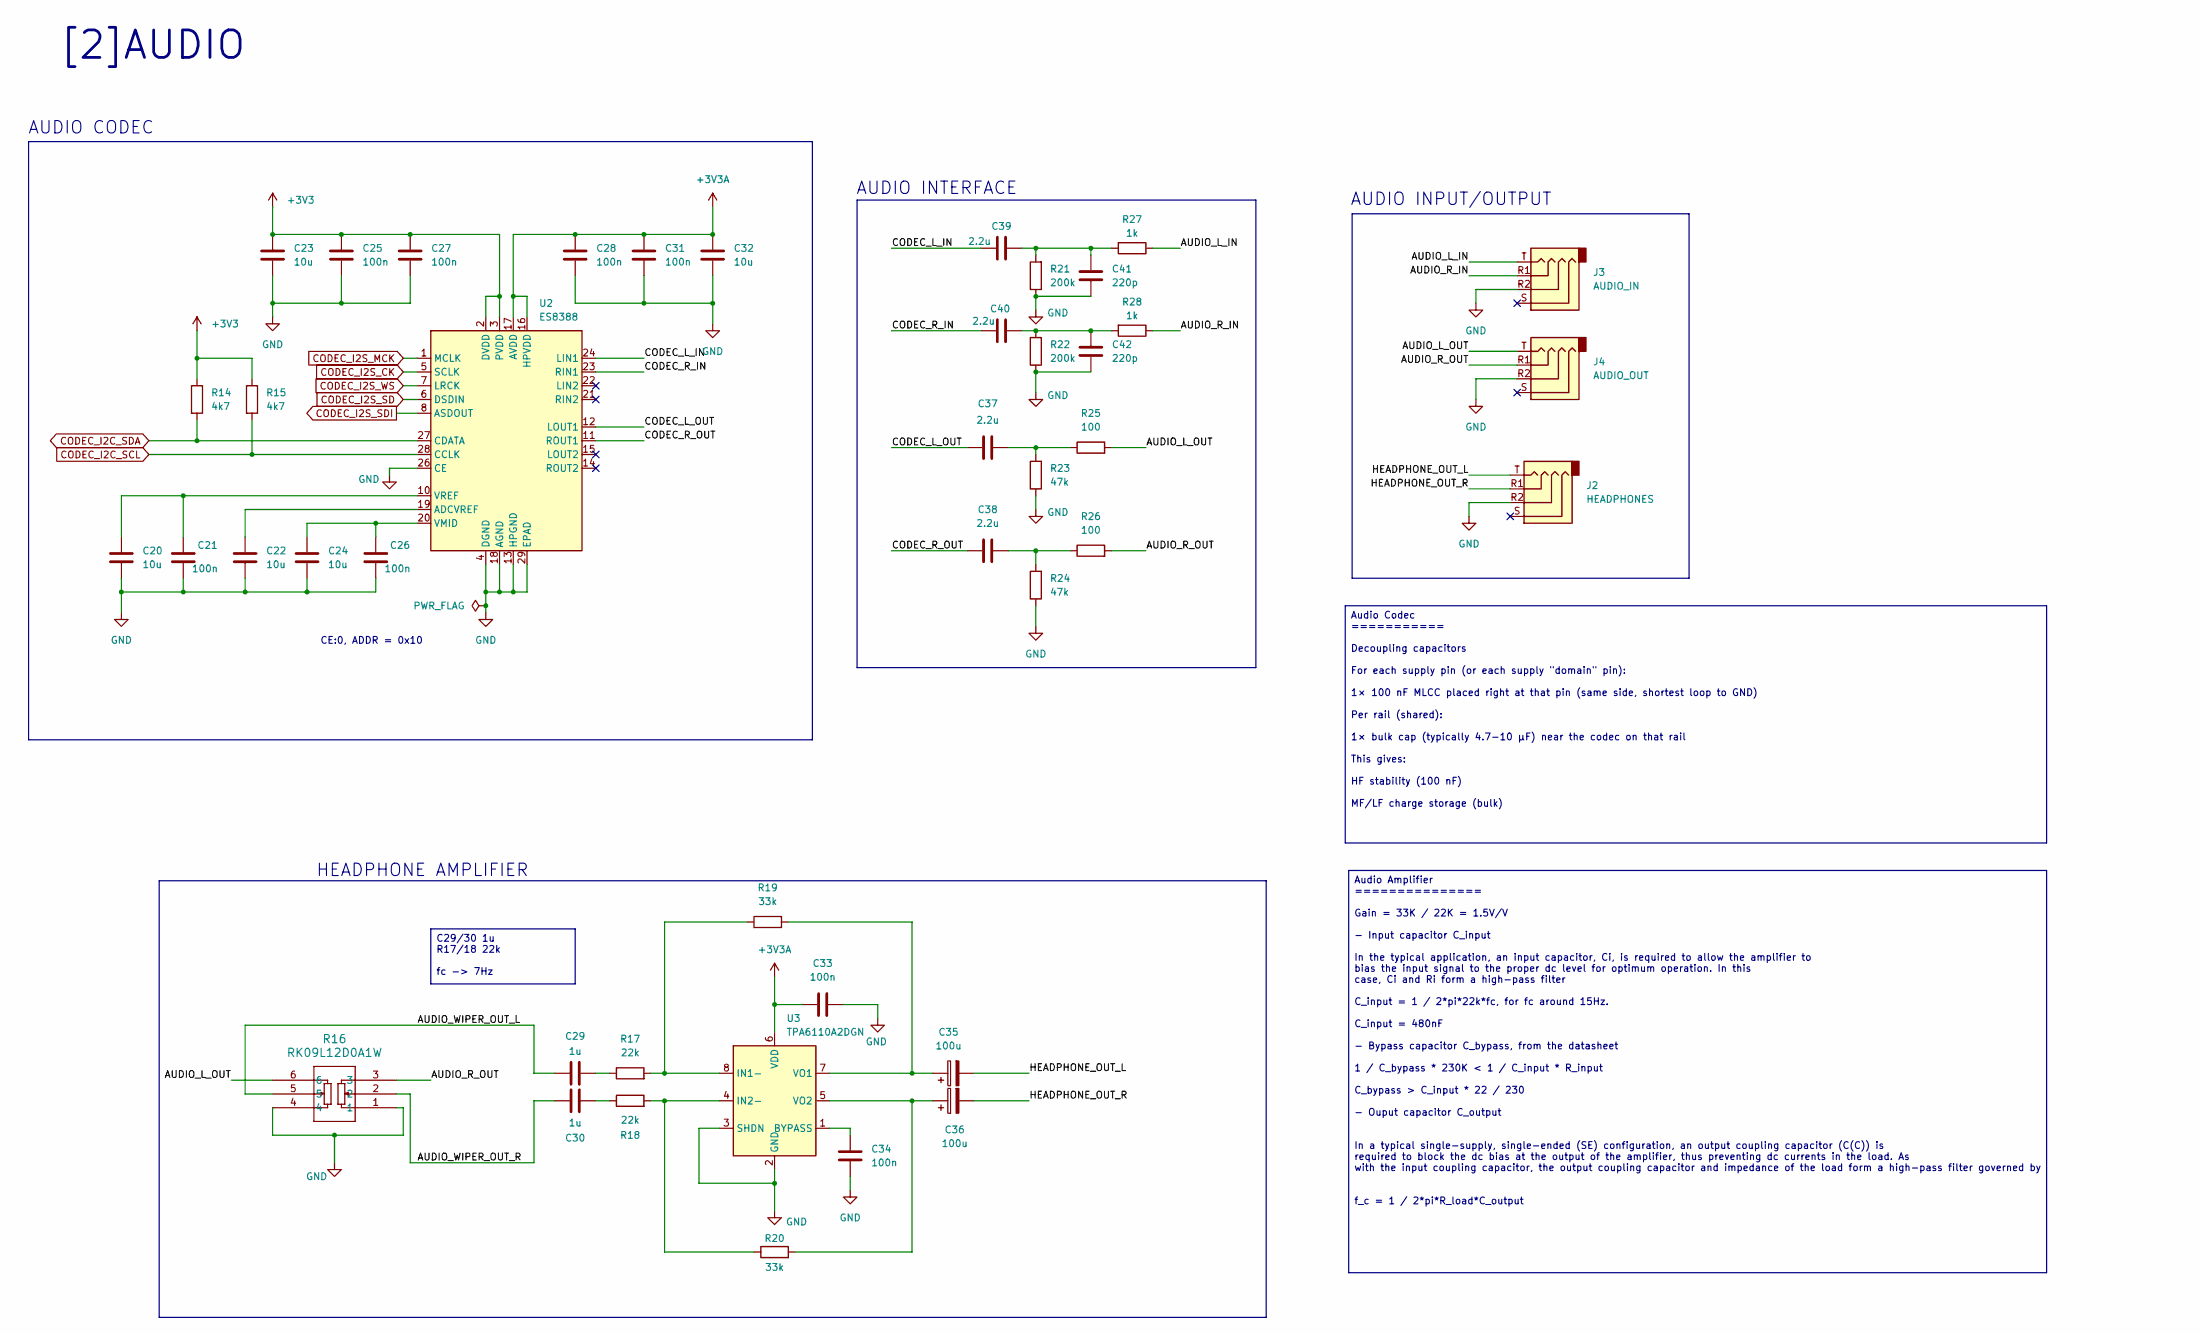
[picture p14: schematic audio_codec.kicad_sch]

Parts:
C20, C22, C23, C24, C32: 10u; C_0603_1608Metric
C21, C25, C26, C27, C28, C31, C33, C34: 100n; C_0402_1005Metric
C29, C30: 1u; C_0402_1005Metric
C35, C36: 100u; CHEMI-F80
C37, C38, C39, C40: 2.2u; C_0805_2012Metric
C41, C42: 220p; C_0402_1005Metric
J2: HEADPHONES; AUDIO-SMD_PJ-320D-1
J3: AUDIO_IN; AUDIO-SMD_PJ-320D-1
J4: AUDIO_OUT; AUDIO-SMD_PJ-320D-1
R14, R15: 4k7; R_0402_1005Metric
R16: RK09L12D0A1W; RK09L12D0A1W_AAL; Manufacturer Part RK09L12D0A1W; LCSC Part C470487
R17, R18: 22k; R_0402_1005Metric
R19, R20: 33k; R_0402_1005Metric
R21, R22: 200k; R_0402_1005Metric
R23, R24: 47k; R_0402_1005Metric
R25, R26: 100; R_0402_1005Metric
R27, R28: 1k; R_0402_1005Metric; Manufacturer Part 0402WGF1001TCE; LCSC Part C11702
U2: ES8388; Manufacturer Part ES8388; LCSC Part C365736
U3: TPA6110A2DGN; HVSSOP-8-1EP_3x3mm_P0.65mm_EP1.57x1.89mm; Manufacturer Part TPA6110A2DGNR; LCSC Part C130212

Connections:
+3V3: C23.1, C25.1, C27.1, R14.1, R15.1, U2.2 (DVDD), U2.3 (PVDD); also elsewhere on the board
+3V3A: C28.1, C31.1, C32.1, C33.2, U2.16 (HPVDD), U2.17 (AVDD), U3.6 (VDD); also elsewhere on the board
/[2] Audio/AUDIO_L_IN: J3.T, R27.1
/[2] Audio/AUDIO_L_OUT: J4.T, R16.6, R25.2
/[2] Audio/AUDIO_R_IN: J3.R1, R28.1
/[2] Audio/AUDIO_R_OUT: J4.R1, R16.3, R26.2
/[2] Audio/AUDIO_WIPER_OUT_L: C29.1, R16.5
/[2] Audio/AUDIO_WIPER_OUT_R: C30.1, R16.2
/[2] Audio/CODEC_L_IN: C39.2, U2.24 (LIN1)
/[2] Audio/CODEC_L_OUT: C37.2, U2.12 (LOUT1)
/[2] Audio/CODEC_R_IN: C40.2, U2.23 (RIN1)
/[2] Audio/CODEC_R_OUT: C38.2, U2.11 (ROUT1)
/[2] Audio/HEADPHONE_OUT_L: C35.2, J2.T
/[2] Audio/HEADPHONE_OUT_R: C36.2, J2.R1
CODEC_I2C_SCL: R15.2, U2.28 (CCLK); also elsewhere on the board
CODEC_I2C_SDA: R14.2, U2.27 (CDATA); also elsewhere on the board
CODEC_I2S_CK: U2.5 (SCLK); also elsewhere on the board
CODEC_I2S_MCK: U2.1 (MCLK); also elsewhere on the board
CODEC_I2S_SD: U2.6 (DSDIN); also elsewhere on the board
CODEC_I2S_SDI: U2.8 (ASDOUT); also elsewhere on the board
CODEC_I2S_WS: U2.7 (LRCK); also elsewhere on the board
GND: C20.2, C21.2, C22.2, C23.2, C24.2, C25.2, C26.2, C27.2, C28.2, C31.2, C32.2, C33.1, C34.1, C41.2, C42.2, J2.R2, J3.R2, J4.R2, R16.1, R16.4, R21.1, R22.1, R23.1, R24.1, U2.4 (DGND), U2.13 (HPGND), U2.18 (AGND), U2.26 (CE), U2.29 (EPAD), U3.2 (GND), U3.3 (SHDN), U3.9 (GND); also elsewhere on the board
unnamed: C29.2, R17.1
unnamed: C30.2, R18.1
unnamed: C37.1, R23.2, R25.1
unnamed: C38.1, R24.2, R26.1
unnamed: C39.1, C41.1, R21.2, R27.2
unnamed: C40.1, C42.1, R22.2, R28.2
unnamed: C22.1, U2.19 (ADCVREF)
unnamed: C24.1, C26.1, U2.20 (VMID)
unnamed: C20.1, C21.1, U2.10 (VREF)
unnamed: C34.2, U3.1 (BYPASS)
unnamed: R17.2, R19.1, U3.8 (IN1-)
unnamed: R18.2, R20.1, U3.4 (IN2-)
unnamed: C35.1, R19.2, U3.7 (VO1)
unnamed: C36.1, R20.2, U3.5 (VO2)

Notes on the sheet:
AUDIO CODEC
AUDIO INPUT/OUTPUT
CE:0, ADDR = 0x10
HEADPHONE AMPLIFIER
AUDIO INTERFACE
[2]AUDIO
C29/30 1u R17/18 22k fc -> 7Hz
Audio Codec =========== Decoupling capacitors For each supply pin (or each supply "domain" pin): 1× 100 nF MLCC placed right at that pin (same side, shortest loop to GND) Per rail (shared): 1× bulk cap (typically 4.7-10 µF) near the codec on that rail This gives: HF stability (100 nF) MF/LF charge 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
Audio Amplifier =============== Gain = 33K / 22K = 1.5V/V - Input capacitor C_input In the typical application, an input capacitor, Ci, is required to allow the amplifier to bias the input signal to the proper dc level for optimum operation. In this case, Ci and Ri form a high-pass filter C_input =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

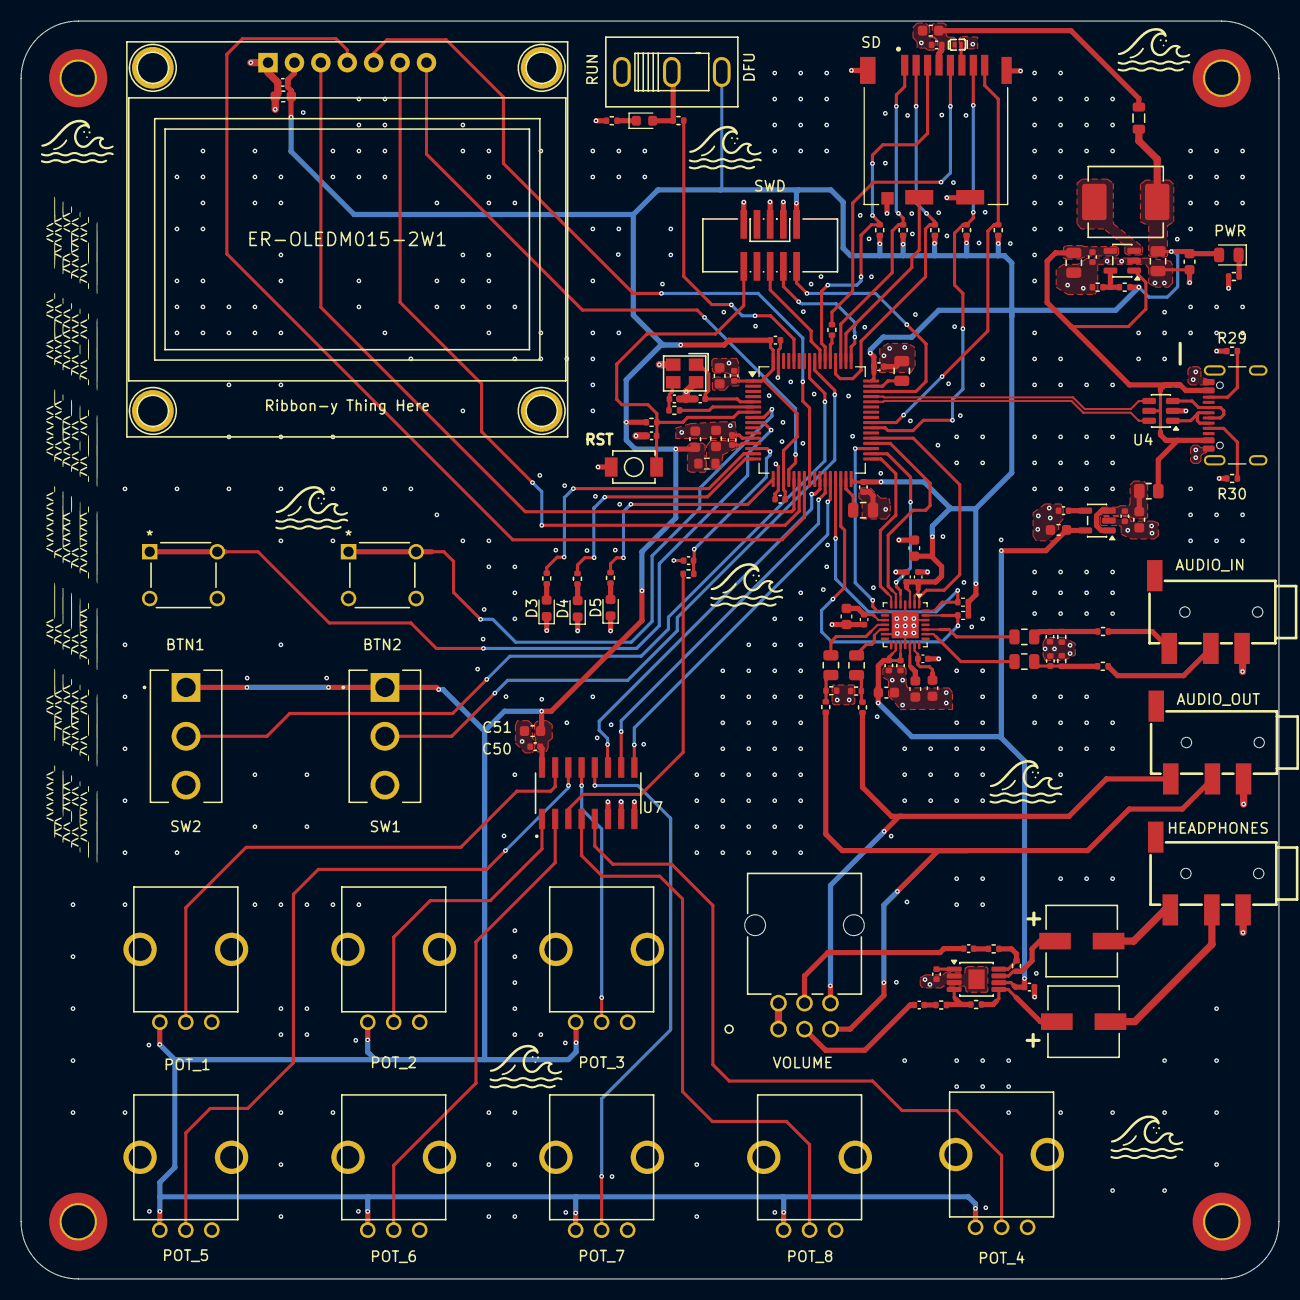
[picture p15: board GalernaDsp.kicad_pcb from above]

Board: 4 copper layers, 121.0 x 121.0 mm, 129 parts (0 on the bottom side), 98 nets.

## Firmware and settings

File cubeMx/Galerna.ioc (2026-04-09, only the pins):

Mcu.UserName=STM32F405RGTx
PA0-WKUP.GPIO_Label=POT_MUX_ADC
PA0-WKUP.Signal=ADCx_IN0
PA1.GPIO_Label=LED_0
PA1.Signal=GPIO_Output
PA11.Signal=USB_OTG_FS_DM
PA12.Signal=USB_OTG_FS_DP
PA13.Signal=SYS_JTMS-SWDIO
PA14.Signal=SYS_JTCK-SWCLK
PA2.GPIO_Label=LED_1
PA2.Signal=GPIO_Output
PA3.GPIO_Label=LED_2
PA3.Signal=GPIO_Output
PA5.GPIO_Label=OLED_SPI_SCK
PA5.Signal=SPI1_SCK
PA6.GPIO_Label=OLED_DC
PA6.Signal=GPIO_Output
PA7.GPIO_Label=OLED_SPI_DATA
PA7.Signal=SPI1_MOSI
PB0.GPIO_Label=POT_MUX_SEL_2
PB0.Signal=GPIO_Output
PB1.GPIO_Label=POT_MUX_SEL_1
PB1.Signal=GPIO_Output
PB10.GPIO_Label=CODEC_I2C_SCL
PB10.Signal=I2C2_SCL
PB11.GPIO_Label=CODEC_I2C_SDA
PB11.Signal=I2C2_SDA
PB12.GPIO_Label=CODEC_I2S_WS
PB12.Signal=I2S2_WS
PB13.GPIO_Label=CODEC_I2S_CK
PB13.Signal=I2S2_CK
PB14.GPIO_Label=CODEC_IS2_SDI
PB14.Signal=I2S2_ext_SD
PB15.GPIO_Label=CODEC_I22_SD
PB15.Signal=I2S2_SD
PB2.GPIO_Label=POT_MUX_SEL_0
PB2.Signal=GPIO_Output
PB3.Signal=SYS_JTDO-SWO
PB4.GPIO_Label=PUSH_BTN_1
PB4.Signal=GPIO_Input
PB5.GPIO_Label=PUSH_BTN_0
PB5.Signal=GPIO_Input
PC0.GPIO_Label=SW_1
PC0.Signal=GPIO_Input
PC1.GPIO_Label=SW_0
PC1.Signal=GPIO_Input
PC10.GPIO_Label=SDCARD_SDIO_D2
PC10.Signal=SDIO_D2
PC11.GPIO_Label=SDCARD_SDIO_D3
PC11.Signal=SDIO_D3
PC12.GPIO_Label=SDCARD_SDIO_CK
PC12.Signal=SDIO_CK
PC4.GPIO_Label=OLED_RST
PC4.Signal=GPIO_Output
PC6.GPIO_Label=CODEC_I2S_MCK
PC6.Signal=I2S2_MCK
PC8.GPIO_Label=SDCARD_SDIO_D0
PC8.Signal=SDIO_D0
PC9.GPIO_Label=SDCARD_SDIO_D1
PC9.Signal=SDIO_D1
PD2.GPIO_Label=SDCARD_SDIO_CMD
PD2.Signal=SDIO_CMD
PH0-OSC_IN.GPIO_Label=MCU_HSE_IN
PH0-OSC_IN.Signal=RCC_OSC_IN
PH1-OSC_OUT.GPIO_Label=MCU_HSE_OUT
PH1-OSC_OUT.Signal=RCC_OSC_OUT

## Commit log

2026-01-31 pushing project
    [GalernaDsp.kicad_pcb, GalernaDsp.kicad_sch, audio_codec.kicad_sch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]
2026-02-01 Audio schematic updated
    [GalernaDsp.kicad_sch, audio_codec.kicad_sch]
2026-02-01 Added oled
    [mcu.kicad_sch]
2026-02-03 SWD connector added
    [mcu.kicad_sch]
2026-02-04 extending library
    [GalernaDsp.kicad_sch, audio_codec.kicad_sch, input_control.kicad_sch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]
2026-02-05 adde boot switch
    [audio_codec.kicad_sch, input_control.kicad_sch, mcu.kicad_sch]
2026-02-08 First pins assingments
    [audio_codec.kicad_sch, mcu.kicad_sch]
2026-02-09 MCU connected
    [audio_codec.kicad_sch, input_control.kicad_sch, mcu.kicad_sch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]
2026-02-09 adding anotations
    [audio_codec.kicad_sch, input_control.kicad_sch, mcu.kicad_sch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]
2026-02-10 ERC fixed
    [audio_codec.kicad_sch, input_control.kicad_sch, mcu.kicad_sch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]
2026-02-11 footprints updated
    [GalernaDsp.kicad_sch, audio_codec.kicad_sch, input_control.kicad_sch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]
2026-02-11 footprint updated
    [power.kicad_sch]
2026-02-12 pcb setup
    [GalernaDsp.kicad_sch, audio_codec.kicad_sch, input_control.kicad_sch]
2026-02-12 decoupling caps route
    [GalernaDsp.kicad_pcb, mcu.kicad_sch]
2026-02-14 constraints updated
    [GalernaDsp.kicad_pcb]
2026-02-14 rules updated
    [GalernaDsp.kicad_pcb]
2026-02-17 codec placed
    [GalernaDsp.kicad_pcb, audio_codec.kicad_sch, mcu.kicad_sch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]
2026-02-18 edge cuts with rectangle
    [GalernaDsp.kicad_pcb]
2026-02-18 control positioned
    [GalernaDsp.kicad_pcb, audio_codec.kicad_sch, mcu.kicad_sch]
2026-02-22 updating names
    [GalernaDsp.kicad_pcb, GalernaDsp.kicad_sch, audio_codec.kicad_sch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]
2026-02-23 net classes added
    [GalernaDsp.kicad_pcb, GalernaDsp.kicad_sch, mcu.kicad_sch]
2026-03-01 routing update
    [GalernaDsp.kicad_pcb, audio_codec.kicad_sch, mcu.kicad_sch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]
2026-03-03 last updates
    [GalernaDsp.kicad_pcb]
2026-03-03 updated placement
    [GalernaDsp.kicad_pcb]
2026-03-14 headphone amplifier routing
    [GalernaDsp.kicad_pcb, audio_codec.kicad_sch]
2026-03-19 pcb updated
    [GalernaDsp.kicad_pcb]
2026-04-05 last update
    [GalernaDsp.kicad_pcb, input_control.kicad_sch, mcu.kicad_sch]
2026-04-08 last status
    [GalernaDsp.kicad_pcb, mcu.kicad_sch]
2026-04-09 Fixing main DRC on pcb
    [GalernaDsp.kicad_pcb]
2026-04-13 DRC fixes
    [GalernaDsp.kicad_pcb]
2026-04-14 All DRC fixed
    [GalernaDsp.kicad_pcb, power.kicad_sch]
2026-04-26 Codec updated to ES8388 on schematic
    [GalernaDsp.kicad_pcb, GalernaDsp.kicad_sch, audio_codec.kicad_sch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]
2026-05-03 ES8388 placed
    [GalernaDsp.kicad_pcb, audio_codec.kicad_sch]
2026-05-13 Adding xlsx bom
    [GalernaDsp.xlsx]
2026-05-13 fillin info in parts
    [GalernaDsp.kicad_pcb, GalernaDsp.kicad_sch, GalernaDsp.xlsx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]
2026-05-31 JLC order
    [BOM-GalernaDsp.csv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]
2026-07-19 Update doc (#1)
    * doc clean up
    * doc updated
    * doc updated
    [GalernaDsp.csv, GalernaDsp.kicad_pcb, GalernaDsp.xlsx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]
2026-07-19 Add KiCad ERC/DRC CI pipeline (#2)
    * Add KiCad ERC/DRC CI pipeline
    Runs kicad-cli ERC/DRC checks via the official kicad/kicad:9.0 Docker
    image on every push/PR to master. Errors fail the build; a full
    severity-all report (including known warnings) is uploaded as a build
    artifact for visibility without blocking merges.
    * Document why J5's mounting-hole pads diverge from the library footprint
    J5's two NPTH pads are widened to *.Cu because the GND plane pours
    across In1.Cu/In2.Cu under the connector; the stock Connector_USB
    footprint's F&B.Cu default would leave the plane fill unrelieved
    across the drilled holes on the inner layers. This trips a
    lib_footprint_mismatch DRC warning that should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
